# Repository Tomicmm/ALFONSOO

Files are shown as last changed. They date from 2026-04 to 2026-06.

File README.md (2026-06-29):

<div align="center">

Typing SVG

<br/>






<br/>

```
╔══════════════════════════════════════════════════════╗
║        🏁  ALFONSOO — Robot Seguidor de Línea  🏁    ║
║         Competencia LNR Argentina · ESP32 · PID      ║
╚══════════════════════════════════════════════════════╝
```

</div>

---

## 📌 Descripción / Description



**ES** — ALFONSOO es un robot autónomo seguidor de línea diseñado y construido para competir en la **Liga Nacional de Robótica (LNR)**. El proyecto abarca diseño electrónico, programación con control PID y chasis impreso en 3D.

**EN** — ALFONSOO is an autonomous line-following robot designed and built to compete in the **Liga Nacional de Robótica (LNR)**. The project covers electronic design, PID control programming, and a fully 3D-printed chassis.

<br clear="right"/>

---

## ⚡ Tech Stack

<div align="center">






</div>

---

## 📂 Estructura del Repositorio / Repo Structure

```
📦 ALFONSOO
 ┣ 🔧 HARDWARE
 ┃   ┣ Esquemas de conexión
 ┃   ┣ Lista de componentes (BOM)
 ┃   └── PCB / Pinout ESP32
 ┃
 ┣ 💻 SOFTWARE
 ┃   ┣ main.cpp (loop principal)
 ┃   ┣ pid.cpp (control PID)
 ┃   └── config.h (parámetros Kp · Ki · Kd)
 ┃
 ┣ 🖨️ CHASIS 3D
 ┃   ┣ Archivos .STL
 ┃   ┣ Archivos .F3D / .STEP
 ┃   └── Fotos del chasis
 ┃
 ┗ 📚 LIBRERIAS
     └── Dependencias del proyecto
```

---

## 🔧 Hardware

### Esquemático / Schematic
> ESP32-DEVKITC-32D · TB6612 Motor Driver · L7805 · Array de 8 sensores IR

<div align="center">
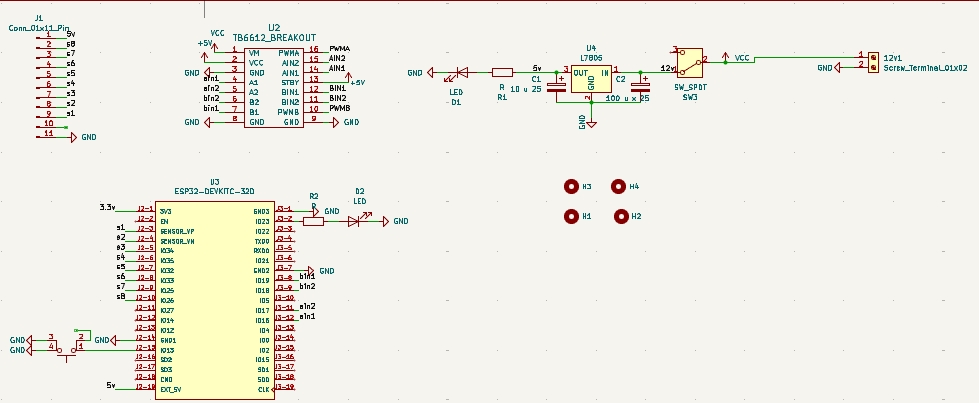
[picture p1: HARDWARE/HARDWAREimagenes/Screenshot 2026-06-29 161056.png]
Esquemático ALFONSOO

</div>

<details>
<summary>📋 Componentes principales / Main components</summary>

| Componente | Descripción |
|---|---|
| **ESP32-DEVKITC-32D** | Microcontrolador principal |
| **TB6612 Breakout** | Driver dual de motores DC |
| **L7805** | Regulador de tensión 5V |
| **S1–S8** | Array de 8 sensores IR |
| **SW_SPDT** | Switch de encendido |
| **12V Screw Terminal** | Entrada de batería |

</details>

---

### PCB Layout
> Diseño "CEBOLLITA EVO+ 2026"

<div align="center">
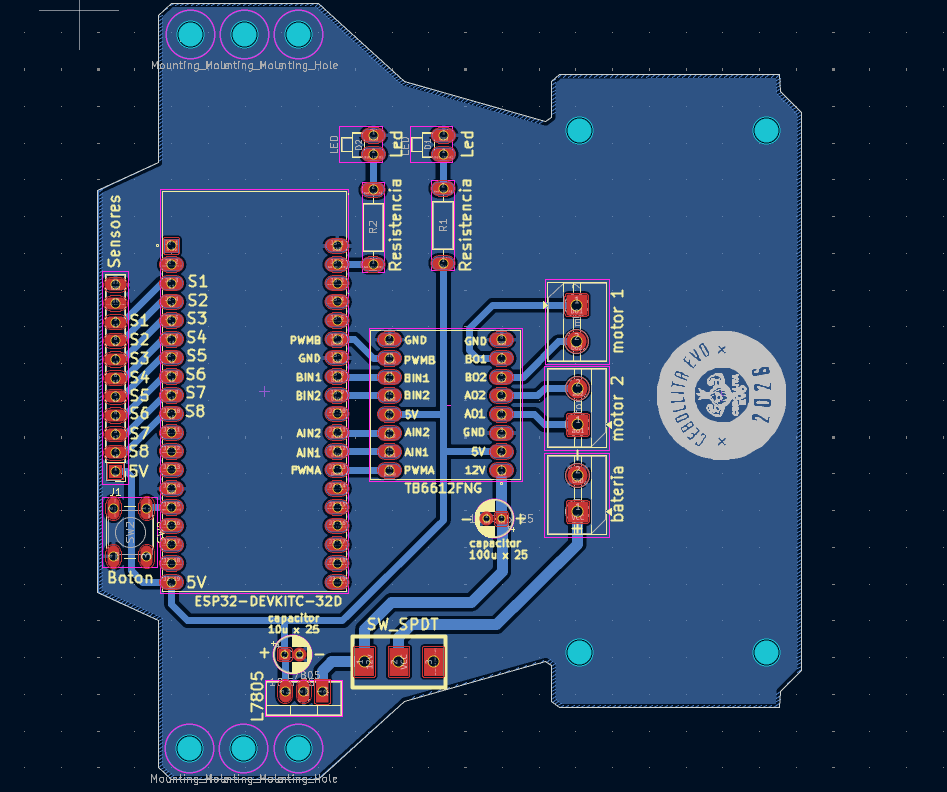
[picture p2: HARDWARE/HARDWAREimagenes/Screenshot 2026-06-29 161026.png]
PCB ALFONSOO

</div>

---

### 🖨️ Chasis 3D / 3D Chassis

<div align="center">
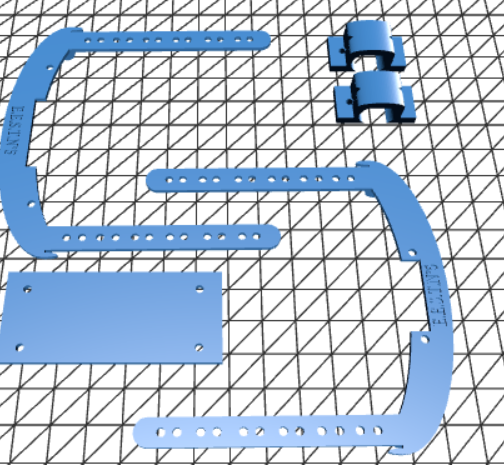
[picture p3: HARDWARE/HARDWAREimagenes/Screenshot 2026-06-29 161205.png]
Chasis 3D ALFONSOO

</div>

> Estructura impresa en 3D con soporte para motores, PCB y sensores.

---

## 🧠 Control PID

<div align="center">

| Parámetro | Descripción | Efecto |
|---|---|---|
| **Kp** | Proporcional | Respuesta inmediata al error |
| **Ki** | Integral | Corrección de error acumulado |
| **Kd** | Derivativo | Suaviza oscilaciones |

```
Error = Setpoint - Posición sensores IR
Output = Kp·e + Ki·∫e·dt + Kd·(de/dt)
```

</div>

---

## 👨‍💻 Equipo / Team

<div align="center">

| 👤 | Nombre | Rol |
|----|---|-----|
| ⚡ | **Tomás Colicchia** | Hardware & Ensamble |
| 🖨️ | **Santiago Avalos** | Chasis 3D & Diseño |
| 🔩 | **Dante Bollo** | Electrónica & Programación |

</div>

---

## 📊 Estado del Proyecto / Project Status

<div align="center">

| Módulo | Estado |
|---|---|
| 🔧 Hardware |  |
| 💻 Software PID |  |
| 🖨️ Chasis 3D |  |
| 🏁 Competencia LNR |  |

</div>

---

<div align="center">

footer



</div>

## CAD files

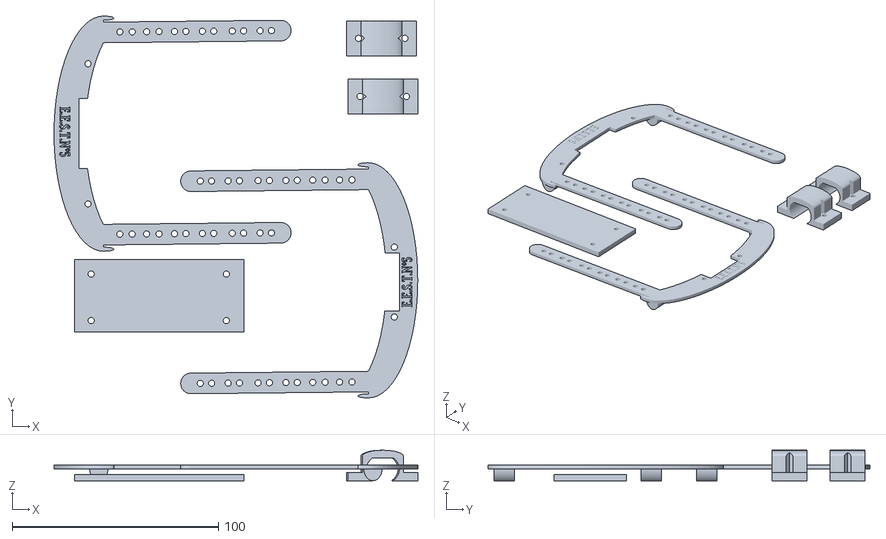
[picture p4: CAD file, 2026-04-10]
CHASIS 3D/soportes (1).stl
176.4 x 185.1 x 14.8

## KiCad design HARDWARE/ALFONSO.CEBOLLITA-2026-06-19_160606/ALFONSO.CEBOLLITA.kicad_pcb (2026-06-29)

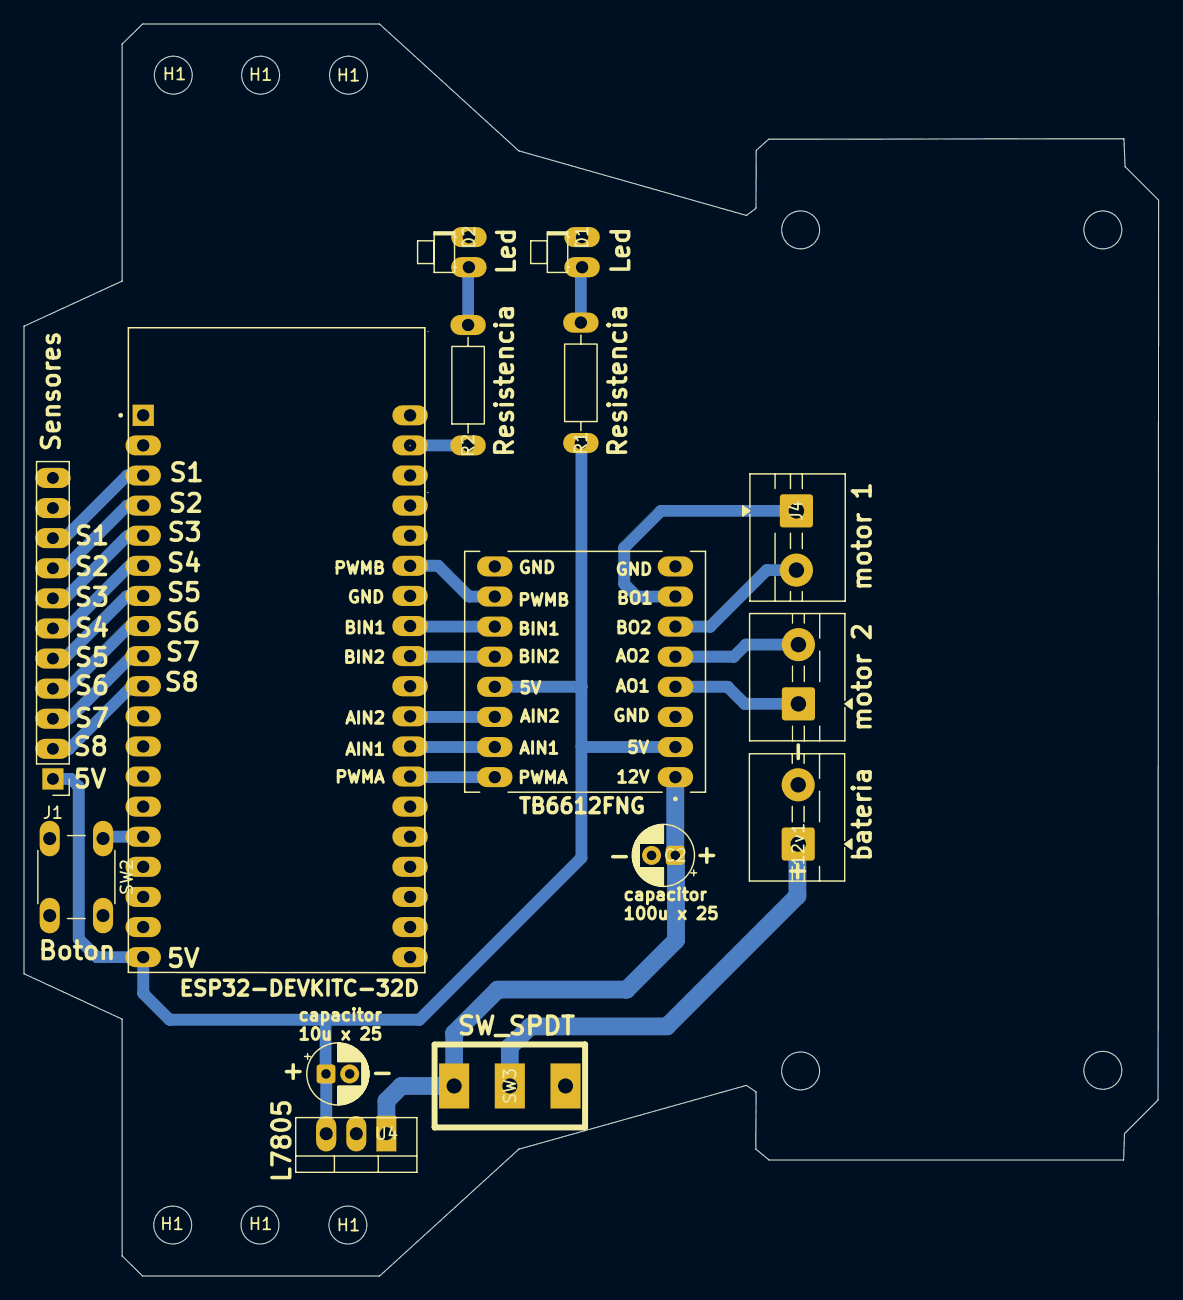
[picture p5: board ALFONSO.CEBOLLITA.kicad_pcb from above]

Board: 2 copper layers, 95.7 x 105.6 mm, 21 parts (0 on the bottom side), 26 nets.

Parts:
12v1: J1; TerminalBlock_MaiXu_MX126-5.0-02P_1x02_P5.00mm
C1: 10 u 25; CP_Radial_D5.0mm_P2.00mm
C2: 100 u x 25; CP_Radial_D5.0mm_P2.00mm
D1, D2: LED; LED_D1.8mm_W1.8mm_H2.4mm_Horizontal_O1.27mm_Z4.9mm
H1, H1#2, H1#3, H1#4, H1#5, H1#6: Mounting_Hole; MountingHole_3.2mm_M3
J1: Conn_01x11_Pin; PinHeader_1x11_P2.54mm_Vertical
J3: motor 1; TerminalBlock_MaiXu_MX126-5.0-02P_1x02_P5.00mm
J4: motor 2; TerminalBlock_MaiXu_MX126-5.0-02P_1x02_P5.00mm
R1, R2: R; R_Axial_DIN0207_L6.3mm_D2.5mm_P10.16mm_Horizontal
SW2: SW_MEC_5E; SW_PUSH_6mm_H5mm
SW3: SW_SPDT; SW_SPDT_TH_Vertical
U2: ROB-14450; MODULE_ROB-14450
U3: ESP32-DEVKITC-32D; MODULE_ESP32-DEVKITC-32D
U4: L7805; TO-220-3_Vertical

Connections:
/5v: C1.1, J1.1, R1.1, U2.2 (VCC), U2.13 (STBY), U3.J2-19 (EXT_5V), U4.3 (OUT)
/12v: C2.1, SW3.1 (A), U2.1 (VM), U4.1 (IN)
/ain1: U2.15 (AI2), U3.J3-12 (IO16)
/ain2: U2.14 (AI1), U3.J3-11 (IO17)
/ao1: J3.1, U2.4 (A01)
/ao2: J3.2, U2.5 (A02)
/bin1: U2.11 (BI2), U3.J3-8 (IO19)
/bin2: U2.12 (BI1), U3.J3-9 (IO18)
/bo1: J4.1, U2.7 (B01)
/bo2: J4.2, U2.6 (B02)
/pwma: U2.16 (PWMA), U3.J3-13 (IO4)
/pwmb: U2.10 (PWMB), U3.J3-6 (IO21)
/s1: J1.9, U3.J2-3 (SENSOR_VP)
/s2: J1.8, U3.J2-4 (SENSOR_VN)
/s3: J1.7, U3.J2-5 (IO34)
/s4: J1.6, U3.J2-6 (IO35)
/s5: J1.5, U3.J2-7 (IO32)
/s6: J1.4, U3.J2-8 (IO33)
/s7: J1.3, U3.J2-9 (IO25)
/s8: J1.2, U3.J2-10 (IO26)
GND: 12v1.2, C1.2, C2.2, D1.1 (K), D2.1 (K), J1.11, SW2.4 (A), U2.3 (GND), U2.8 (GND), U2.9 (GND), U3.J2-14 (GND1), U3.J3-1 (GND3), U3.J3-7 (GND2), U4.2 (GND)
unnamed: D1.2 (A), R1.2
unnamed: D2.2 (A), R2.2
unnamed: SW2.1, U3.J2-15 (IO13)
unnamed: R2.1, U3.J3-2 (IO23)
VCC: 12v1.1, SW3.2 (B)
